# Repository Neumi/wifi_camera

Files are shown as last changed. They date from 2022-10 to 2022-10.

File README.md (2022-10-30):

# wifi_camera

### A camera that can see WiFi signals. Just the sensor unit. Currently planned for 8x8=64 pixels.

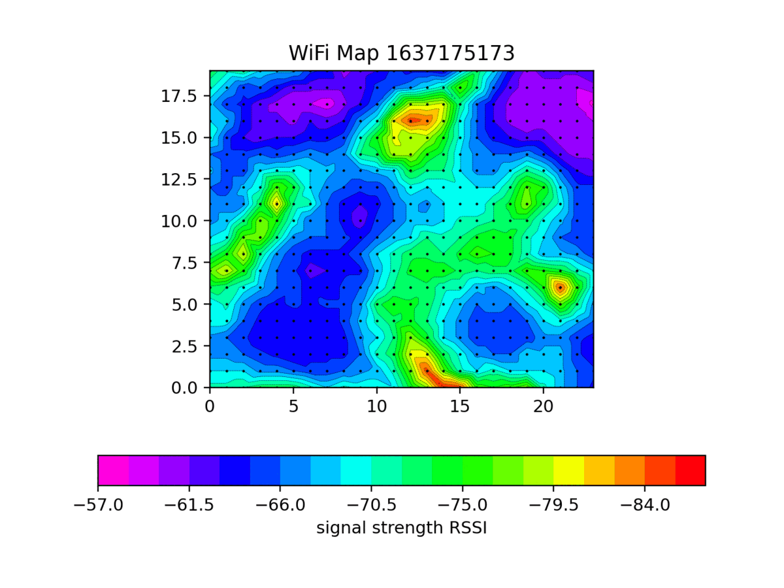
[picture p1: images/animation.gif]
result of a scanned 3D frame

3D capture of a wifi signal in a 20x20x20 cm grid.

## What it does
The sensor array captures RSSI values from near by WiFi networks and sends the collected pixel data to a master that processes and visualizes the captured data. The goal is to build a sensor, that makes WiFi signal visible in more or less real time.

## Why? 
WiFi signals are invisible to humans. I think it would be fun to make them visible and play around with it. Projects I have in mind unsing the sensor array: real time analysis of antennas and obstacles..., real time object/person detection/tracking by reading WiFi shadows and reflections, using the standing wave to 'surf' it to get position data back for i.e. robots.

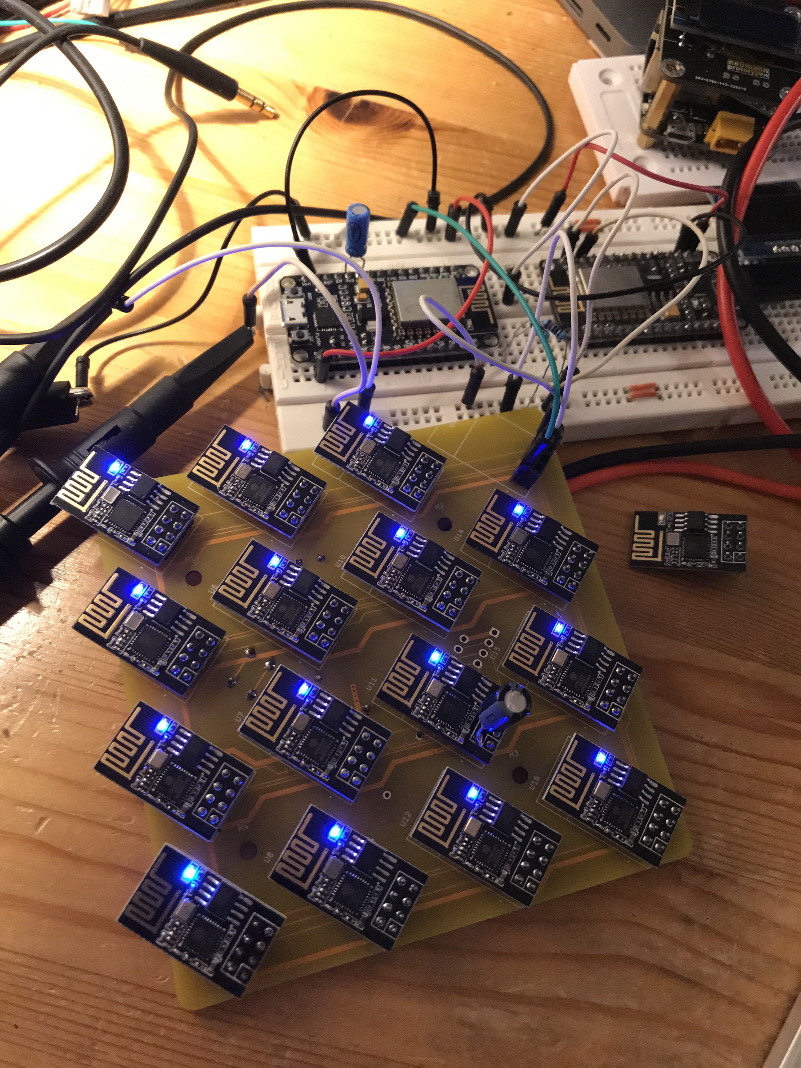
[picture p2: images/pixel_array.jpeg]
4x4 pixel array


## How?
Before this, I built a rig to scan and visualize WiFi signal propagation in 3D 

https://hackaday.com/2021/11/22/visualizing-wifi-with-a-converted-3d-printer/

https://github.com/Neumi/3D_wifi_scanner

This got me interested in building a real time, sensor array to take a whole frame at once without having to scan a slice one position after another.

To capture a whole slice at once, I built this array unsing four PCBs with 4x4 ESP8266 sensor nodes connected via i2c where every pixel is an i2c slave and a master that asks the pixels one by one for the captured values.
 
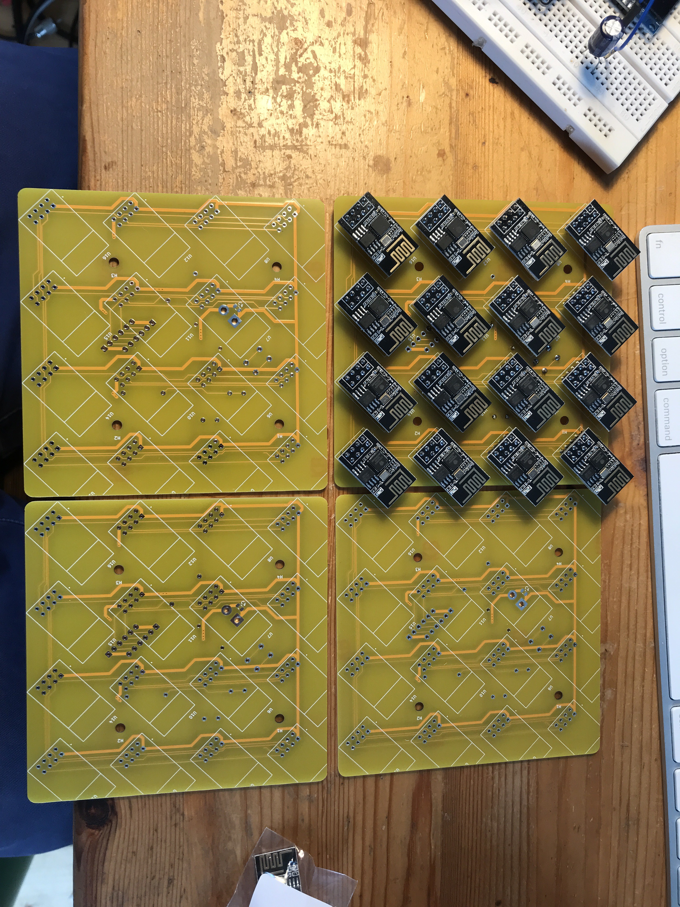
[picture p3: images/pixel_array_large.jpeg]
four 4x4 pixel arrays


I'm currently waiting fore more ESP8266s to arrive.

## Results
The results look pretty granular currently, as I only used 4x4 pixels, which is a bit low. When more ESPs arrive, I will take more images.
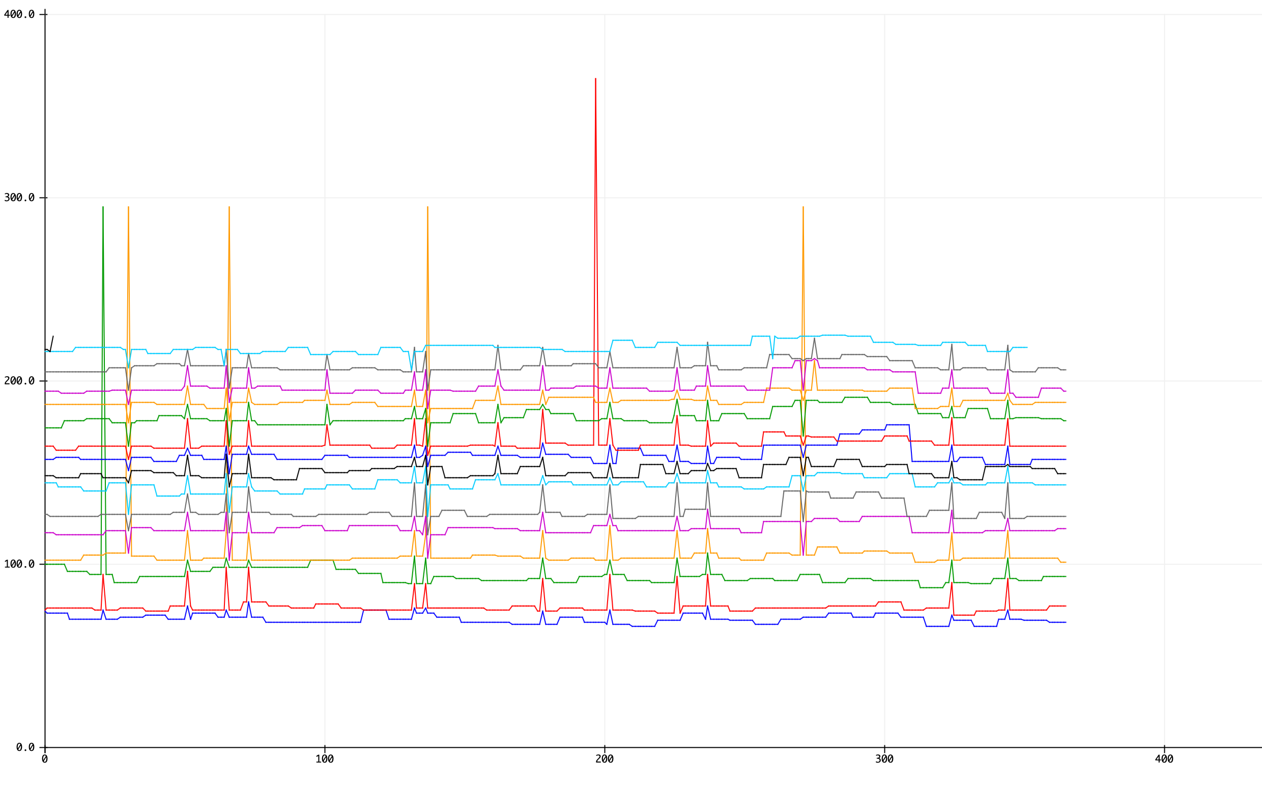
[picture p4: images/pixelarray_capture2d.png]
16 pixels

16 Pixels, x-axis is time, Y axis is RSSI with an offset between each pixel for visibility.
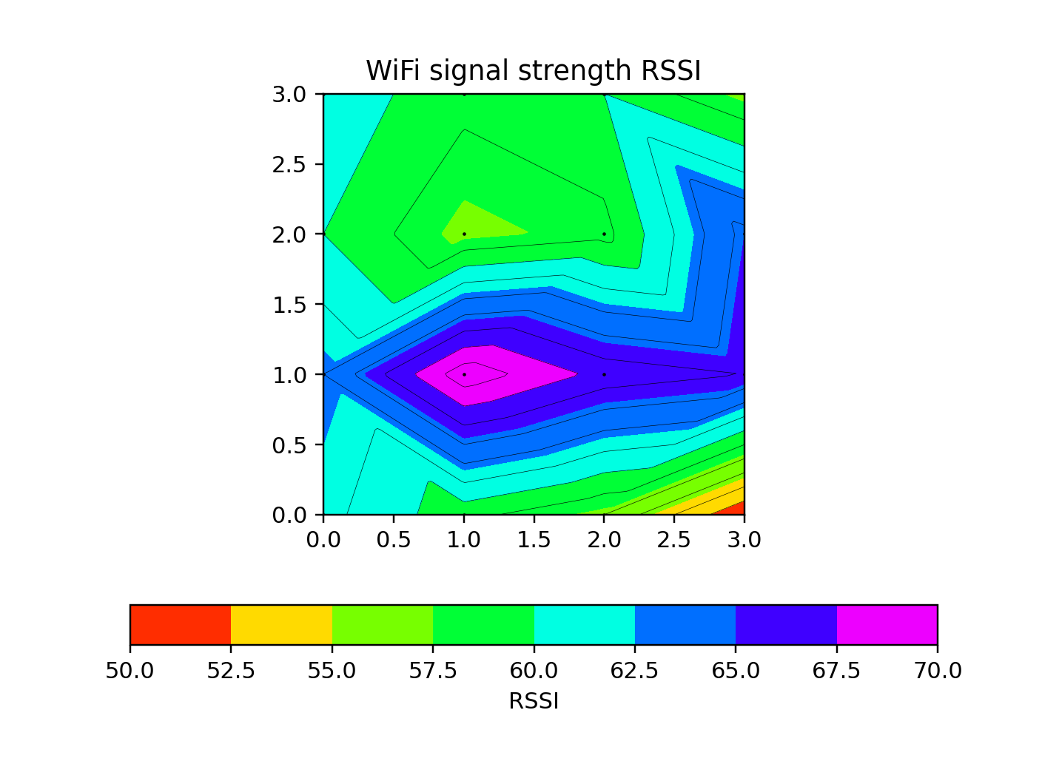
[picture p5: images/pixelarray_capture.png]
four 4x4 pixel arrays

16 Pixels with correct orientation in a 2D plot. 

## Video of 4x4 test grid:
VIDEO (https://www.youtube.com/shorts/Hjyqzx_mGRc)

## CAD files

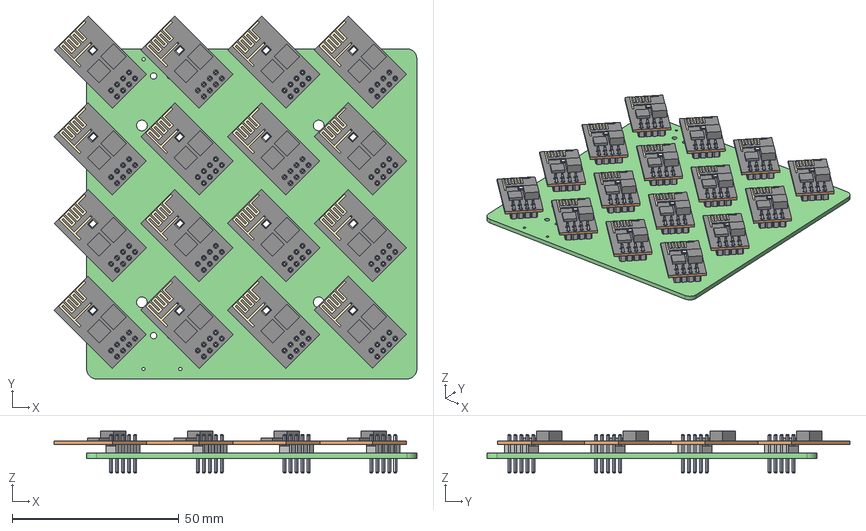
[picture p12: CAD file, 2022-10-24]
electronics/wifi_camera.step
108.8 x 108.8 x 12.5 mm
_autosave-wifi_camera PCB

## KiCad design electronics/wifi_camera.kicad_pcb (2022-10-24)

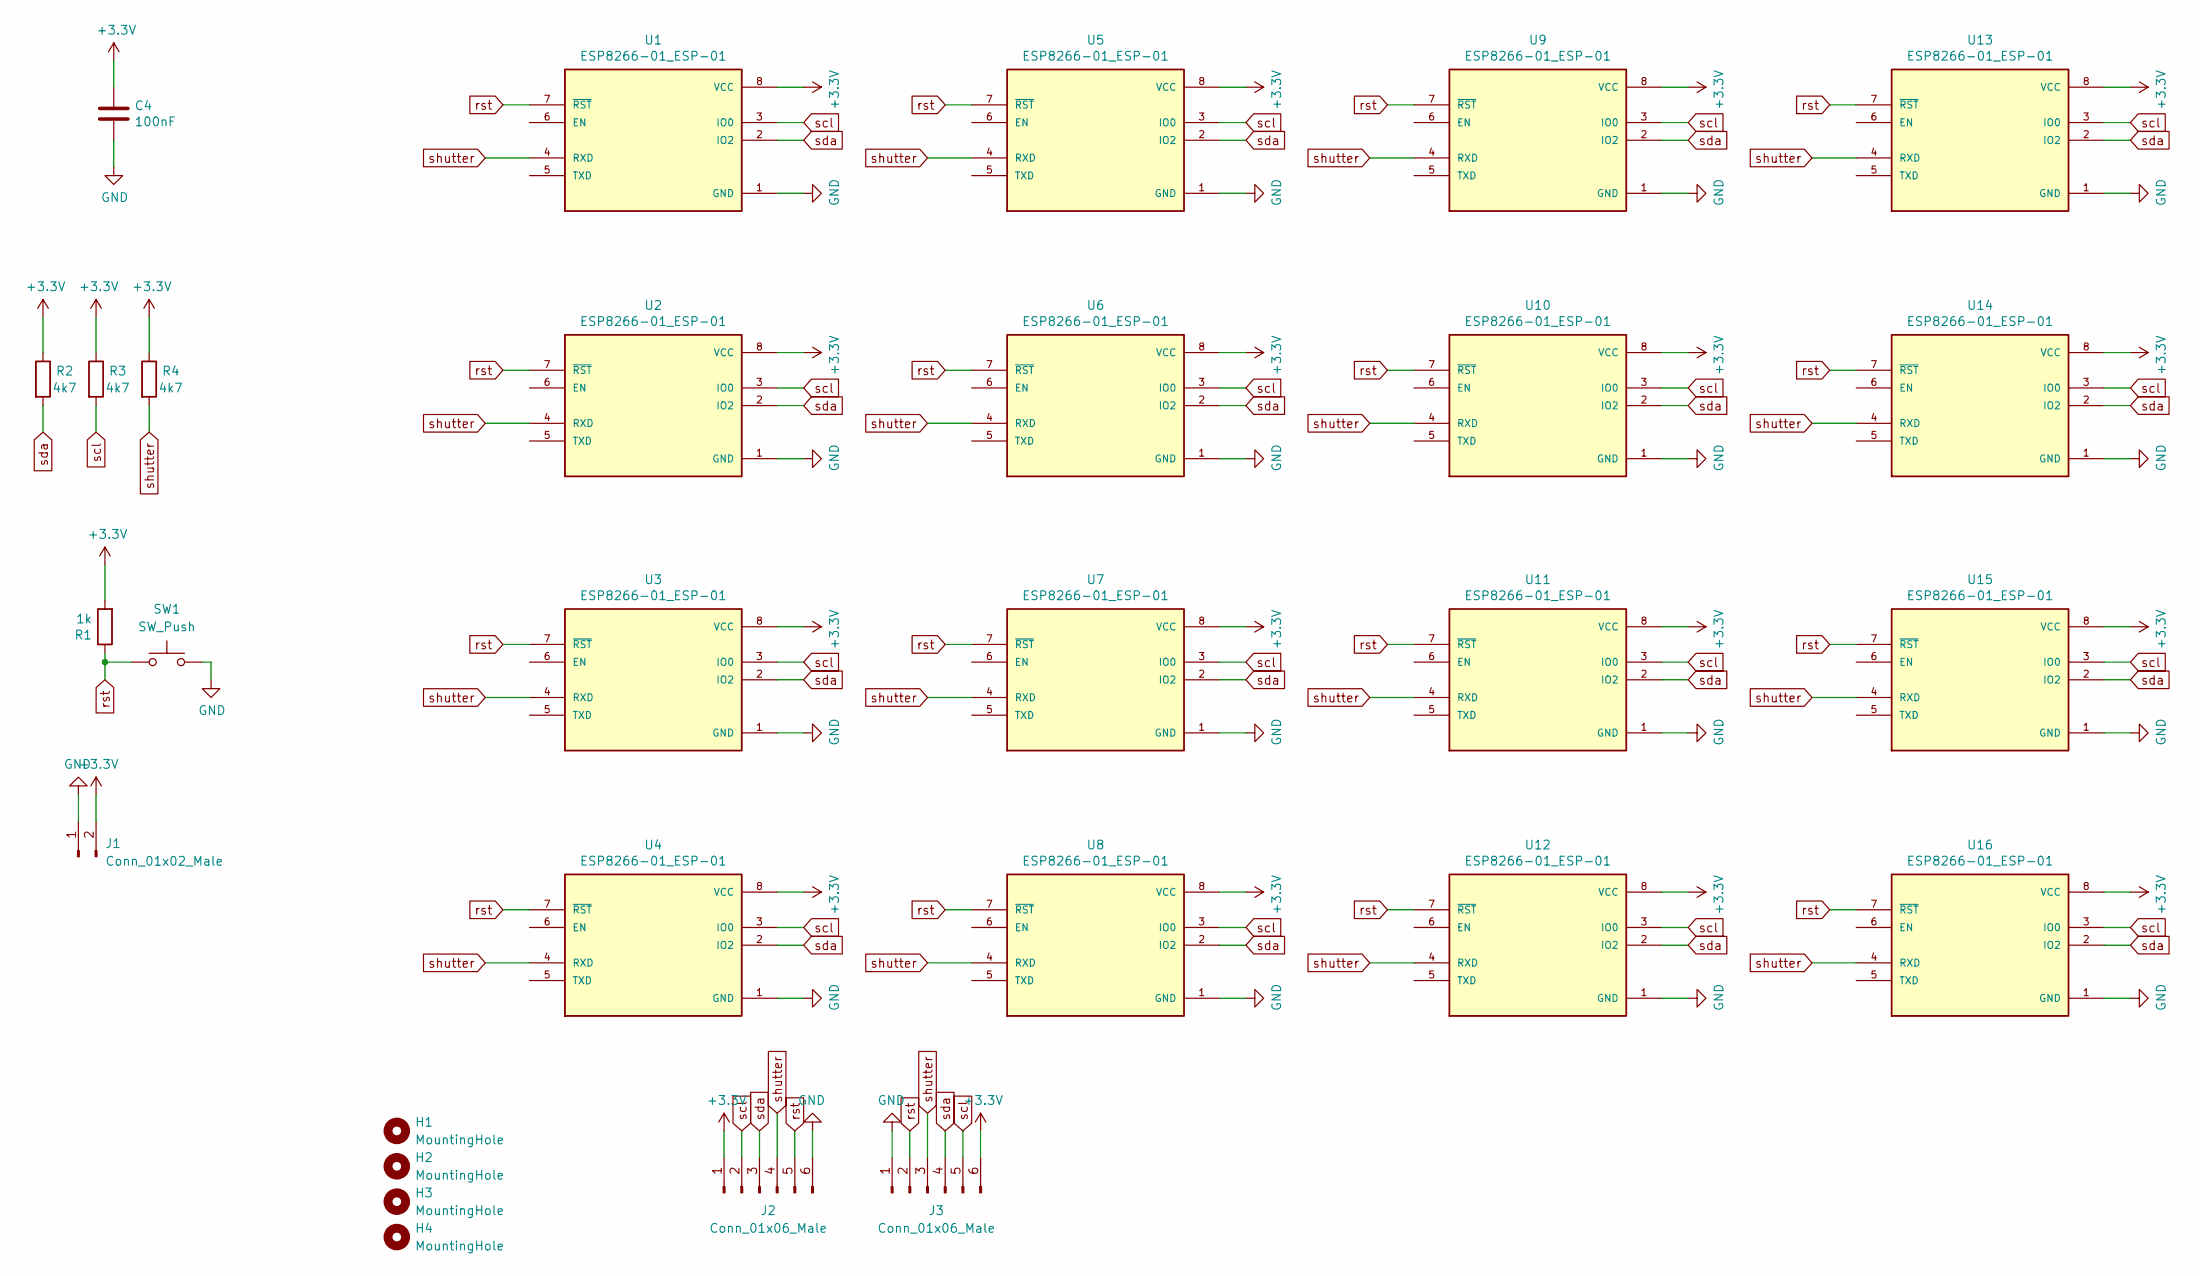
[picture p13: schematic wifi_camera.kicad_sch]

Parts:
C4: 100nF; C_0805_2012Metric
H1, H2, H3, H4: MountingHole; MountingHole_3.2mm_M3
J1: Conn_01x02_Male; AMASS_XT30PW-M_1x02_P2.50mm_Horizontal
J2, J3: Conn_01x06_Male; JST_EH_B6B-EH-A_1x06_P2.50mm_Vertical
R1: 1k; R_Axial_DIN0309_L9.0mm_D3.2mm_P12.70mm_Horizontal
R2, R3, R4: 4k7; R_Axial_DIN0309_L9.0mm_D3.2mm_P12.70mm_Horizontal
SW1: SW_Push; SW_PUSH_6mm
U1, U2, U3, U4, U5, U6, U7, U8, U9, U10, U11, U12, U13, U14, U15, U16: ESP8266-01_ESP-01; XCVR_ESP8266-01_ESP-01; PARTREV V1.2

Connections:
+3V3: C4.1, J1.2, J2.1, J3.6, R1.2, R2.1, R3.1, R4.1, U1.8 (VCC), U2.8 (VCC), U3.8 (VCC), U4.8 (VCC), U5.8 (VCC), U6.8 (VCC), U7.8 (VCC), U8.8 (VCC), U9.8 (VCC), U10.8 (VCC), U11.8 (VCC), U12.8 (VCC), U13.8 (VCC), U14.8 (VCC), U15.8 (VCC), U16.8 (VCC)
GND: C4.2, J1.1, J2.6, J3.1, SW1.2, U1.1 (GND), U2.1 (GND), U3.1 (GND), U4.1 (GND), U5.1 (GND), U6.1 (GND), U7.1 (GND), U8.1 (GND), U9.1 (GND), U10.1 (GND), U11.1 (GND), U12.1 (GND), U13.1 (GND), U14.1 (GND), U15.1 (GND), U16.1 (GND)
rst: J2.5, J3.2, R1.1, SW1.1, U1.7 (~RST), U2.7 (~RST), U3.7 (~RST), U4.7 (~RST), U5.7 (~RST), U6.7 (~RST), U7.7 (~RST), U8.7 (~RST), U9.7 (~RST), U10.7 (~RST), U11.7 (~RST), U12.7 (~RST), U13.7 (~RST), U14.7 (~RST), U15.7 (~RST), U16.7 (~RST)
scl: J2.2, J3.5, R3.2, U1.3 (IO0), U2.3 (IO0), U3.3 (IO0), U4.3 (IO0), U5.3 (IO0), U6.3 (IO0), U7.3 (IO0), U8.3 (IO0), U9.3 (IO0), U10.3 (IO0), U11.3 (IO0), U12.3 (IO0), U13.3 (IO0), U14.3 (IO0), U15.3 (IO0), U16.3 (IO0)
sda: J2.3, J3.4, R2.2, U1.2 (IO2), U2.2 (IO2), U3.2 (IO2), U4.2 (IO2), U5.2 (IO2), U6.2 (IO2), U7.2 (IO2), U8.2 (IO2), U9.2 (IO2), U10.2 (IO2), U11.2 (IO2), U12.2 (IO2), U13.2 (IO2), U14.2 (IO2), U15.2 (IO2), U16.2 (IO2)
shutter: J2.4, J3.3, R4.2, U1.4 (RXD), U2.4 (RXD), U3.4 (RXD), U4.4 (RXD), U5.4 (RXD), U6.4 (RXD), U7.4 (RXD), U8.4 (RXD), U9.4 (RXD), U10.4 (RXD), U11.4 (RXD), U12.4 (RXD), U13.4 (RXD), U14.4 (RXD), U15.4 (RXD), U16.4 (RXD)

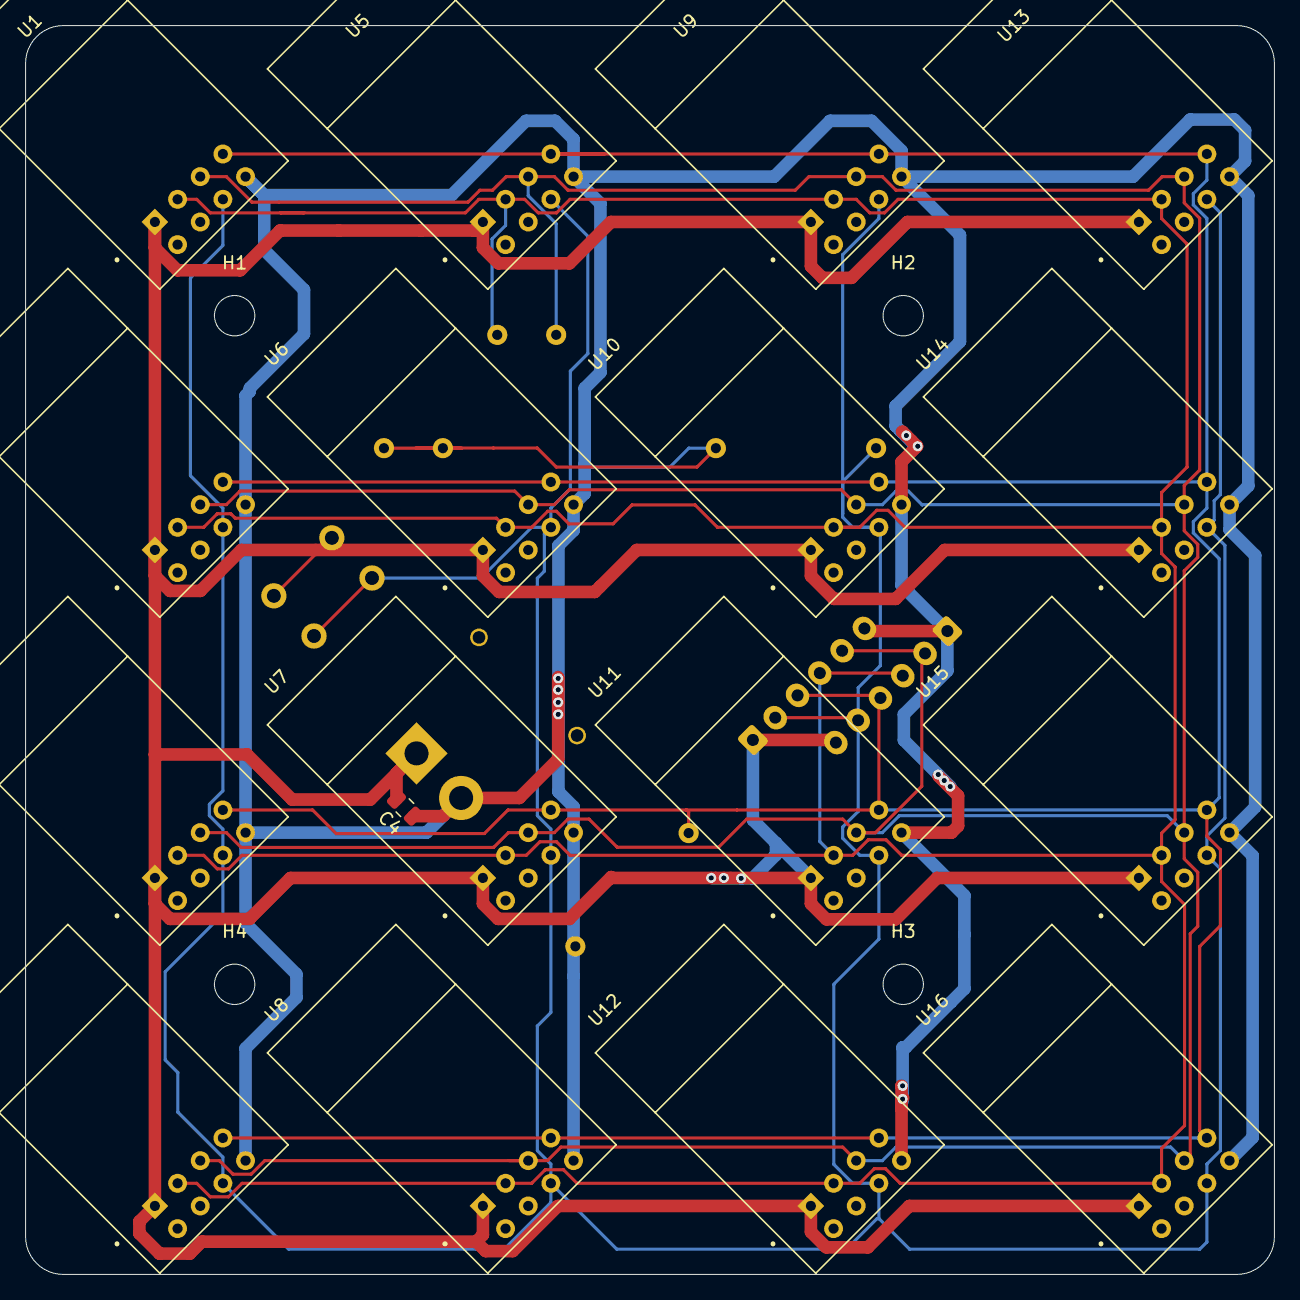
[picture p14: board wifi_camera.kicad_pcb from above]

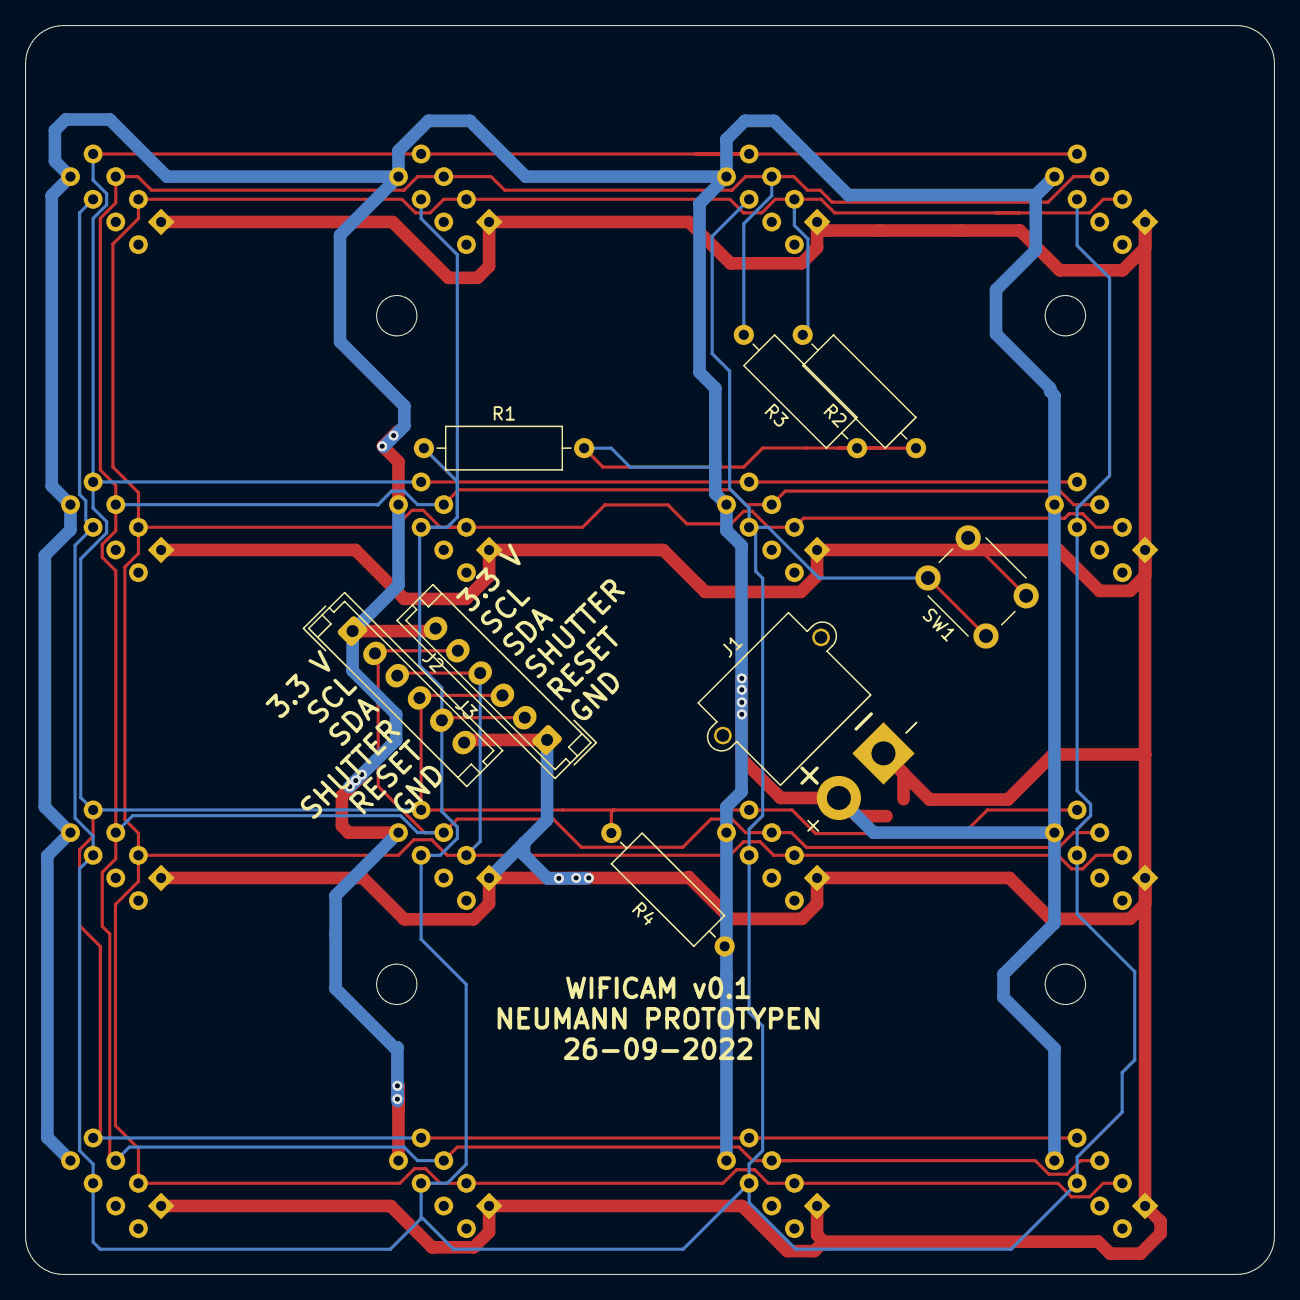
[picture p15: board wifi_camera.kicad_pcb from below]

Board: 2 copper layers, 99.0 x 99.0 mm, 29 parts (8 on the bottom side), 6 nets.

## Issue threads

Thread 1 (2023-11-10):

Directional antenna and esp8285

tytarenko, 2023-11-10:
Hello! That's fantastic! I was truly impressed when I saw your project. It inspired me so much that I ended up ordering 16 esp-01s. I have a couple of ideas. Initially, I attempted to find the radiation pattern of the PCB antenna and came across this visualization.

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

So, probably, creating a custom PCB module using the esp8285 (because you only need one chip and a few SMD components like resistors, capacitors, etc.) And it would be something like this.
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

Neumi, 2023-11-10:
Fantastic! It's great to have some actual measurements of the EPS8266. This is actually one of the bigger flaws if we want to measure a "slice" of WiFi because the measurements change if we move the grid around.

I made some PCBs a while ago to do exactly what you described. I ordered 64 ESPs, but the Aliexpress seller tried to scam me :D ... I ended up with 16 on a grid. (but have enough PCBs to get a 64 grid)

This is what the grid looked in the end.
https://www.youtube.com/shorts/Hjyqzx_mGRc

I had some problems with the power supply, as the ESPs combined needed approximately 3A on startup. And they are very susceptible to an unstable power supply. I used i2c for communication, where every ESP is a slave on the i2c bus. But ESP8266 do not support slave mode natively and get very unstable again ... it was quite a mess :D

Neumi, 2023-11-10:
If I'd put more work into it, I'd try to make the software upload OTA or something similar. Or flash them all at the same time (not sure if they would accept that). Programming every pixel one by one was kind of a pain.
The addressing should also be automated. I think I had a daisy chain pin to each subsequent ESP to do so. But the code and addresses were all hard coded in the beginning.

tytarenko, 2023-11-10:
What do you think about this connection a few devices
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

Neumi, 2023-11-10:
But you need CS for each device if you want to fetch data by device. This would require 1. many traces on the PCB 2. a master unit with n GPIO pins for every slave and 3. I think the cheap ESP01 modules do have the SPI pins on the pinout. And the flash is also connected via SPI. But that is not in use all the time I assume.
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

Neumi, 2023-11-10:
Or do you mean to flash the devices via SPI? That would actually be a cool idea. But how do we separate all the devices after flashing? :D I mean it would be possible to build a kind of hardware bootloader that gives each ESP access to one central SPI flash after another... but that sounds a bit too much for this task I guess :D

Neumi, 2023-11-10:
TBH that would be a very cool experiment to load firmware to many ESP from one central SPI flash. I wonder if someone has done it before.

tytarenko, 2023-11-10:
> TBH that would be a very cool experiment to load firmware to many ESP from one central SPI flash. I wonder if someone has done it before.

I think it needs to control access. But, as I said at the beginning, I would like to use esp8685 it’s the same esp8266 but it has integrated flash so you don’t need external chip.

tytarenko, 2023-11-10:
I drew this scheme
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

my idea is next
attiny1616 has i2c interface and could be as slave. So it has own address. For uploading firmware to each node master has to send command to attiny1616 pull down gpio0 to ground. And after that master can upload firmware to node via uart

Neumi, 2023-11-10:
I think we could also use the the ESPs for that. by connecting a gpio to the reset button of the next ESP, we can upload firmware one after another by only releasing the next ESP when the firmware was uploaded to the previous. But we might also need a central reset for that I guess.

tytarenko, 2023-11-10:
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
https://www.infineon.com/dgdl/Infineon-AN205429_FR_CY91460_SPI_Daisy_chain_Communication-ApplicationNotes-v04_00-EN.pdf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

As I see here that uses only one chip select pin in parallel for all devices.  Or I miss something?

Neumi, 2023-11-10:
Ah ok this is interesting. They daisy chain the MISO and MOSIs. Never seen that in action, actually. I'm wondering if SPI supports that natively or if they need special chips for that. But if it works the same with the ESPs that would actually be very cool and useful. Does the ESP8285 have SPI out on the boards you have? Because the ESP-01s do not I think.

Neumi, 2023-11-10:
Another option would be to use a GPIO expander like mcp23016. This would either give us more CS pins or a controlled reset for each ESP to flash them.

I2c communication is quite handy I think because you only need two wires. (even though ESPs don't support slave mode natively, it works at a reasonable speed).

The firmware upload has to happen via some master controller (that we need anyway to collect the pixel data while running). Then the master sends all controllers to reset and flash mode with the multiplexers and flashes the controllers one after another via normal serial and bootloader.

tytarenko, 2023-11-10:
![Uploading E1413E31-88BA-4DD6-9114-57FD29BCA775.jpeg…]()

tytarenko, 2023-11-10:
And I think about radiation pattern.  I tried to draw my idea
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

Probably it could make radiation for z most mirrored.

tytarenko, 2023-11-11:
I have question about distance between modules. In your version of pcb it is 26mm. Is it enough for wave 125mm?

tytarenko, 2023-11-20:
About fiberglass, it's my mistake. I made a poor illustration. It should be mirrored fiberglass with copper.
Have you thought about updating the firmware via an OTA server?

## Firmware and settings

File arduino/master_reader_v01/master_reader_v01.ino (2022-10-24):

#include <Wire.h>
#include <PolledTimeout.h>


// nodemcu
#define SDA_PIN 4
#define SCL_PIN 5
const int16_t I2C_MASTER = 128;

const int deviceCount = 16;

void setup() {
  Serial.begin(115200);  // start serial for output
  Wire.begin(SDA_PIN, SCL_PIN, I2C_MASTER);        // join i2c bus (address optional for master)
  Wire.setClock(10000);

}

boolean initialize = true;
void loop() {
  using periodic = esp8266::polledTimeout::periodicMs;
  static periodic nextPing(500);

  if (nextPing) {
    for (int deviceAddress = 1; deviceAddress < deviceCount + 1; deviceAddress++)
    {
      Wire.requestFrom(deviceAddress, 1);
      while (Wire.available()) { // slave may send less than requested
        byte rssi = Wire.read(); // receive a byte as character
        //Serial.print("RSSI: ");
        Serial.print(rssi);         // print the rssi
        Serial.print(",");
      }
    }
    Serial.println();
  }

  /*
    if (nextPing) {
    Wire.requestFrom(I2C_SLAVE, 1);    // request 6 bytes from slave device #8

    while (Wire.available()) { // slave may send less than requested
      byte rssi = Wire.read(); // receive a byte as character
      Serial.print(rssi);         // print the rssi
    }
    Serial.println();
    }
  */
}

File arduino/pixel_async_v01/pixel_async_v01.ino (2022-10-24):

#include <Wire.h>
#include <ESP8266WiFi.h>


//ESP NODEMCU
// #define SDA_PIN 4
// #define SCL_PIN 5

//ESP01
#define SDA_PIN 2
#define SCL_PIN 0


const int16_t I2C_MASTER = 128;
const int16_t I2C_SLAVE = 4;

const int shutterPin = 3;

boolean shutterState = 0;
boolean oldShutterState = 0;

int timeDelay = 0;


int scanStartMillis = 0;
int scanEndMillis = 0;
int scanTime = 0;
byte scanRssi = 0;

boolean scanDone = true;

String networkName = "Testwerk";

void setup() {
  Serial.begin(115200);
  Wire.begin(SDA_PIN, SCL_PIN, I2C_SLAVE);
  Wire.onRequest(requestEvent);
  Wire.setClock(10000);

  randomSeed(analogRead(A0));
  timeDelay = random(10, 400);
  delay(timeDelay);

  pinMode(shutterPin, INPUT);

  WiFi.mode(WIFI_STA);
  WiFi.disconnect();

  delay(timeDelay);


  // WiFi.scanNetworks(/*async=*/true, /*hidden=*/true);

}
void loop() {
  if (scanDone) {
    scanAsync();
  }

}


void requestEvent() {
  int scanAge = millis() - scanEndMillis;
  Wire.write(scanRssi);
  // Wire.write(scanAge);
  // Wire.write("hello"); // respond with message of 6 bytes
  // as expected by master
}


void scanAsync() {
  //Serial.println("Start Scan...");
  scanStartMillis = millis();
  WiFi.scanNetworksAsync(processScanResult, true);
  scanDone = false;

}

void processScanResult(int networksFound)
{
  scanEndMillis = millis();
  //Serial.printf("%d network(s) found\n", networksFound);
  for (int i = 0; i < networksFound; i++)
  {
    if (WiFi.SSID(i) == networkName) {
      scanRssi = abs(WiFi.RSSI(i));
      scanTime = millis() - scanStartMillis;
    }
    //Serial.printf("%d: %s, Ch:%d (%ddBm) %s\n", i + 1, WiFi.SSID(i).c_str(), WiFi.channel(i), WiFi.RSSI(i), WiFi.encryptionType(i) == ENC_TYPE_NONE ? "open" : "");
  }
  //Serial.println("Start Done...");
  //Serial.print("Scan time: ");
  //Serial.println(scanTime);
  //Serial.print("Scan RSSI: ");
  //Serial.println(scanRssi);
  //Serial.println();
  scanDone = true;
}

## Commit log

2022-10-24 added electroncs, layout, schematics and source code for pixels and master using i2c
    [wifi_camera-B_Cu.gbr, wifi_camera-B_Mask.gbr, wifi_camera-B_Paste.gbr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]
2022-10-24 added python code for visualization, stack processing and real time preview
    [csv_file_1637174521.csv, csv_file_1637174923.csv, csv_file_1637175173.csv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]
